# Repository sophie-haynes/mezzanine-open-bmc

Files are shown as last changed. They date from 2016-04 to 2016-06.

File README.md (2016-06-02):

# mezzanine-open-bmc

This project contains the kicad files for the BMC project.

##Project Status
* _Schematic:_ Complete. Would be wise to have a quick review (just to be safe :) ).
* _PCB:_ Connected. DRC appears to throw some small issues, once resolved gerber files can be produced.
* _Footprints:_ Some footprints have been added to the project.

__NOTE:__ There is some strangeness between the schematic and PCB; the ratsnest shows incorrect connections in the PCB so be sure to refer to the schematic when connecting components.

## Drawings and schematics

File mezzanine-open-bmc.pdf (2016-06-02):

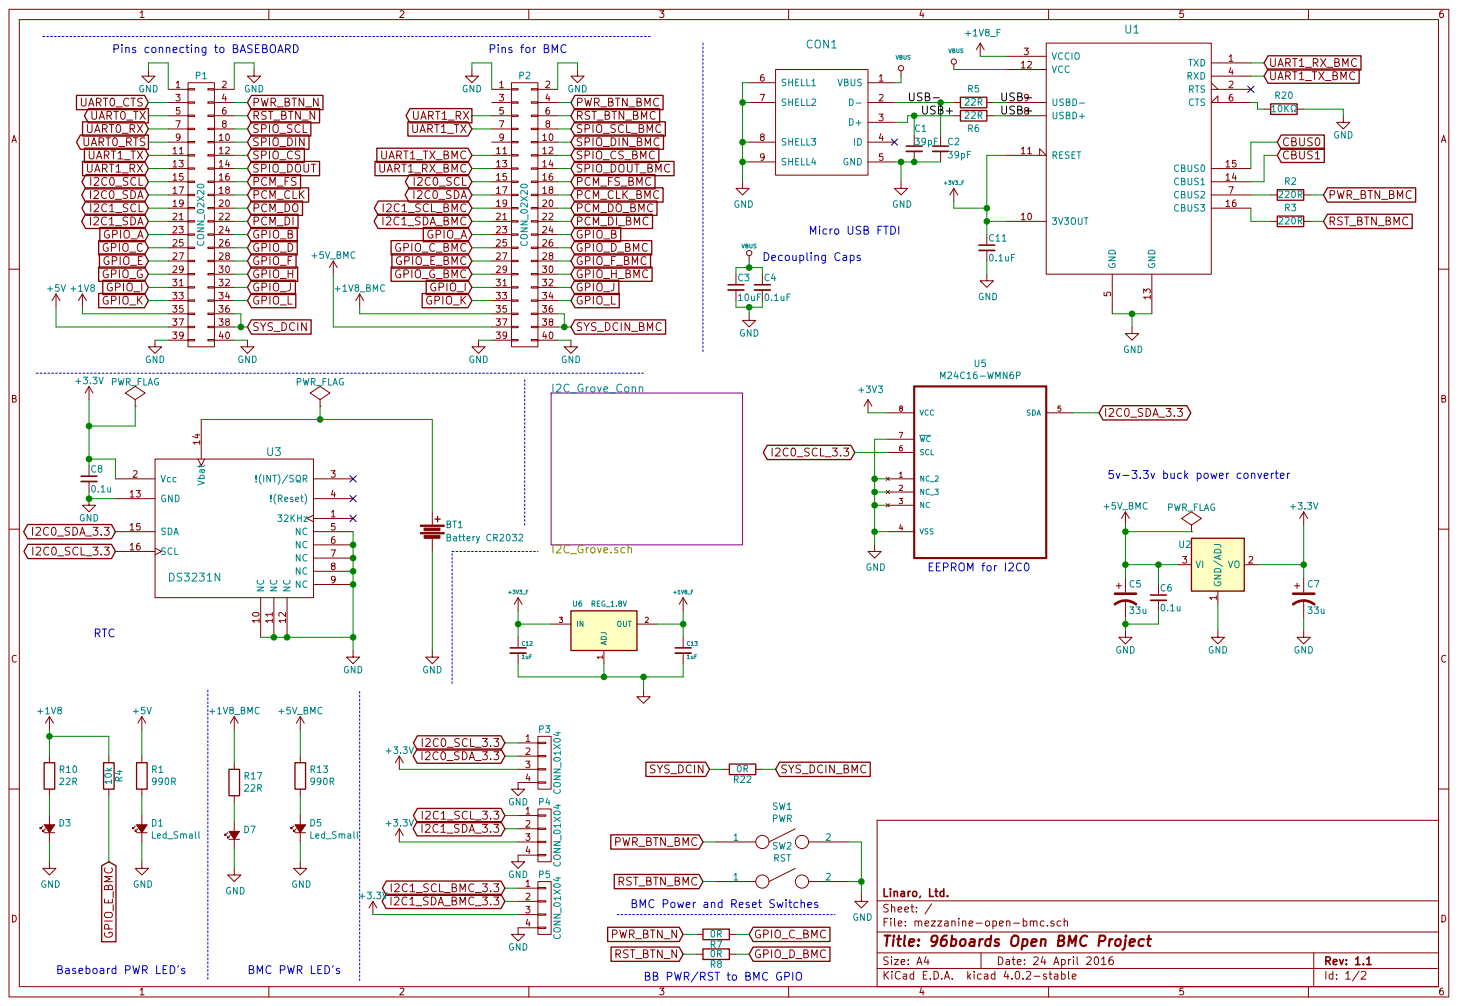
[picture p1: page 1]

BB PWR/RST to BMC GPIO +5V GPIO_E_BMC

File: mezzanine-open-bmc.sch Sheet: / Linaro, Ltd.

Id: 1/2 Title: 96boards Open BMC Project

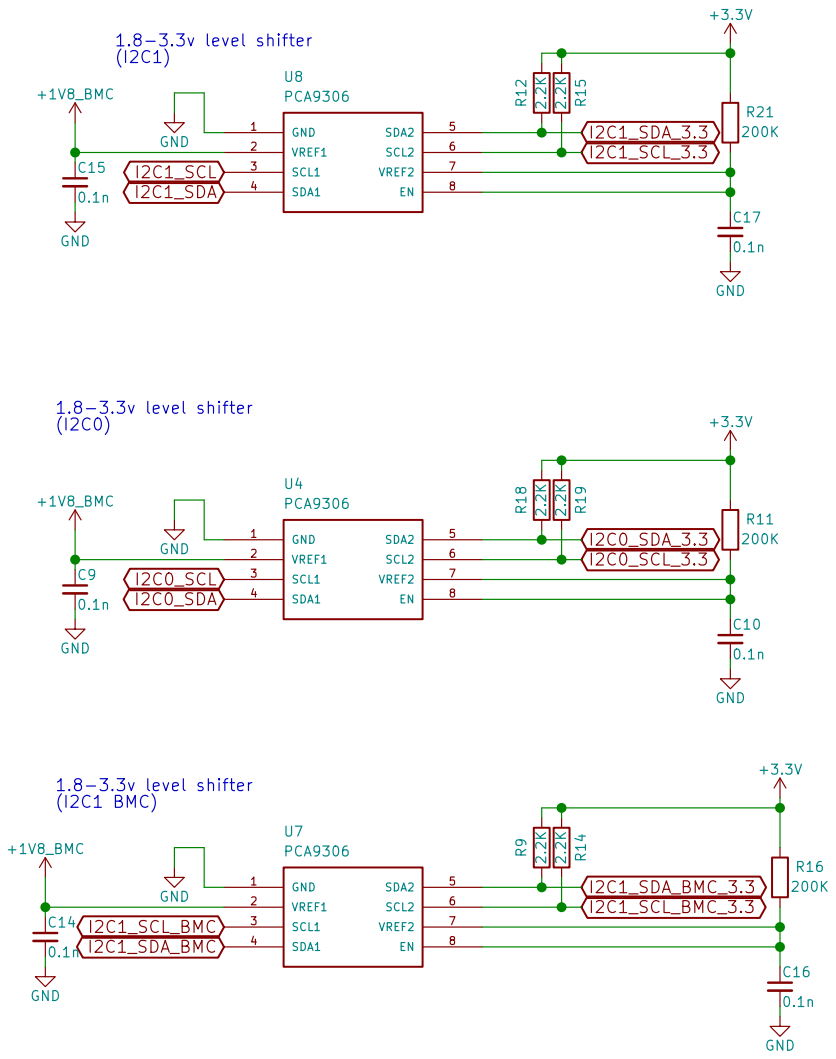
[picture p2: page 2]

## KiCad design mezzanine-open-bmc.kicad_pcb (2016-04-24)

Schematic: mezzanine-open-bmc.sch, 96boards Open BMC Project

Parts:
BT1: Battery CR2032
C1, C2: 39pF; C_0603
C3: 10uF; C_0603
C4, C11: 0.1uF; C_0603
C5, C7: 33u; C_0603
C6: 0.47u; C_0603
C8: 0.1u; C_0603
C9, C10: 0.1n; C_0603
C12, C13: 1uF; C_0603
C14, C15: 100n; C_0603
CON1: USB_MICRO_B_ST-USB-001E
D1, D3, D5, D7: Led_Small; LED_0603
P1: CONN_02X20; Pin_Header_SMD_2x20_Pitch2mm; Mfr Part # P220-1220A0xMxxxx2
P2: CONN_02X20; Pin_Header_SMD_2x20_Pitch2mm; Mfr Part # F240-1220A0xMUx1
P3, P4: CONN_01X04; Grove4P
R1, R13: 90Ω; R_0603
R2, R3: 220R; R_0603
R4: 10k; R_0603
R5, R6: 22R; R_0603
R7, R8: 0R; R_0603
R10, R17: 620R; R_0603
R11: 200k; R_0603
R18, R19: 2.2K; R_0603
R20: 10KΩ; R_0603
SW1: PWR; SW_SPST_B3U-1000P
SW2: RST; SW_SPST_B3U-1000P
U1: FT230XS; SSOP-16_3.9x4.9mm_Pitch0.635mm_Seeed
U2: PMIC-CJT1117-3.3(SOT223); SOT-223
U3: DS3231N; SO-16-W
U4: PCA9306
U5: M24C16-WMN6P; SOIC127P600X175-8N
U6: REG_1.8V; SOT-23_Seeed; Mfr Part # XC6206P182MR
U7: TXS0104PW; SSOP-14_5.3x6.2mm_Pitch0.65mm

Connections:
+3V3: C7.1, C8.1, R11.1, R18.1, R19.2, U2.2, U3.2 (Vcc), U5.8
+3V3_F: C12.1, U6.3
CBUS0: U1.15 (CBUS0)
CBUS1: U1.14 (CBUS1)
GND: BT1.2, C1.2, C2.2, C3.2, C4.2, C5.2, C6.1, C7.2, C8.2, C9.2, C10.2, C11.2, C12.2, C13.2, C14.2, C15.2, CON1.5 (GND), CON1.6 (SHELL1), CON1.7 (SHELL2), CON1.8 (SHELL3), CON1.9 (SHELL4), D1.1 (K), D3.1 (K), D5.1 (K), D7.1 (K), P1.1, P1.2, P1.39, P1.40, P2.1, P2.2, P2.39, P2.40, P3.4, P4.4, R20.1, SW1.2, SW2.2, U1.5 (GND), U1.13 (GND), U2.1, U3.5 (NC), U3.6 (NC), U3.7 (NC), U3.8 (NC), U3.9 (NC), U3.10 (NC), U3.11 (NC), U3.12 (NC), U3.13 (GND), U4.1 (GND), U5.1, U5.2, U5.3, U5.4, U5.7, U6.1, U7.7
GPIO_A: P1.23, P2.23
GPIO_B: P1.24, P2.24
GPIO_C: P1.25
GPIO_C_BMC: P2.25, R7.1
GPIO_D: P1.26
GPIO_D_BMC: P2.26, R8.1
GPIO_E: P1.27
GPIO_E_BMC: P2.27, R4.2
GPIO_F: P1.28
GPIO_F_BMC: P2.28
GPIO_G: P1.29
GPIO_G_BMC: P2.29
GPIO_H: P1.30
GPIO_H_BMC: P2.30
GPIO_I: P1.31, P2.31
GPIO_J: P1.32, P2.32
GPIO_K: P1.33, P2.33
GPIO_L: P1.34, P2.34
I2C0_SCL: P1.15, P2.15, U4.3 (SCL1), U5.6, U7.3
I2C0_SCL/5: P3.1, U7.12
I2C0_SCL_3.3: R19.1, U3.16 (SCL), U4.6 (SCL2)
I2C0_SDA: P1.17, P2.17, U4.4 (SDA1), U5.5, U7.2
I2C0_SDA/5: P3.2, U7.13
I2C0_SDA_3.3: R18.2, U3.15 (SDA), U4.5 (SDA2)
I2C1_SCL: P1.19, U7.5
I2C1_SCL/5: P4.1, U7.10
I2C1_SCL_BMC: P2.19
I2C1_SDA: P1.21, U7.4
I2C1_SDA/5: P4.2, U7.11
I2C1_SDA_BMC: P2.21
unnamed: BT1.1, U3.14 (Vbat)
unnamed: C1.1, CON1.3 (D+), R6.2
unnamed: C2.1, CON1.2 (D-), R5.2
unnamed: C10.1, R11.2, U4.7 (VREF2), U4.8 (EN)
unnamed: C11.1, U1.10 (3V3OUT), U1.11 (RESET)
unnamed: D1.2 (A), R1.2
unnamed: D3.2 (A), R10.2
unnamed: D5.2 (A), R13.2
unnamed: D7.2 (A), R17.2
unnamed: R2.2, U1.7 (CBUS2)
unnamed: R3.2, U1.16 (CBUS3)
unnamed: R5.1, U1.9 (USBD-)
unnamed: R6.1, U1.8 (USBD+)
unnamed: R20.2, U1.6 (CTS)
PCM_CLK: P1.18
PCM_CLK_BMC: P2.18
PCM_DI: P1.22
PCM_DI_BMC: P2.22
PCM_DO: P1.20
PCM_DO_BMC: P2.20
PCM_FS: P1.16
PCM_FS_BMC: P2.16
PWR_BTN_BMC: P2.4, R2.1, SW1.1
PWR_BTN_N: P1.4, R7.2
RST_BTN_BMC: P2.6, R3.1, SW2.1
RST_BTN_N: P1.6, R8.2
SPIO_CS: P1.12
SPIO_CS_BMC: P2.12
SPIO_DIN: P1.10
SPIO_DIN_BMC: P2.10
SPIO_DOUT: P1.14
SPIO_DOUT_BMC: P2.14
SPIO_SCL: P1.8
SPIO_SCL_BMC: P2.8
SYS_DCIN: P1.36, P1.38
SYS_DCIN_BMC: P2.36, P2.38
UART0_CTS: P1.3
UART0_RTS: P1.9
UART0_RX: P1.7
UART0_TX: P1.5
UART1_RX: P1.13, P2.5
UART1_RX_BMC: P2.13, U1.1 (TXD)
UART1_TX: P1.11, P2.7
UART1_TX_BMC: P2.11, U1.4 (RXD)
VBUS: C3.1, C4.1, CON1.1 (VBUS), U1.12 (VCC)

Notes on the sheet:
Pins connecting to BASEBOARD
Pins for BMC
BMC Power and Reset Switches
BB PWR/RST to BMC GPIO
Baseboard PWR LED's
Micro USB FTDI
1.8v-3.3v level shifter
5v-3.3v buck power converter
RTC
BMC PWR LED's
Decoupling Caps
EEPROM for I2C0

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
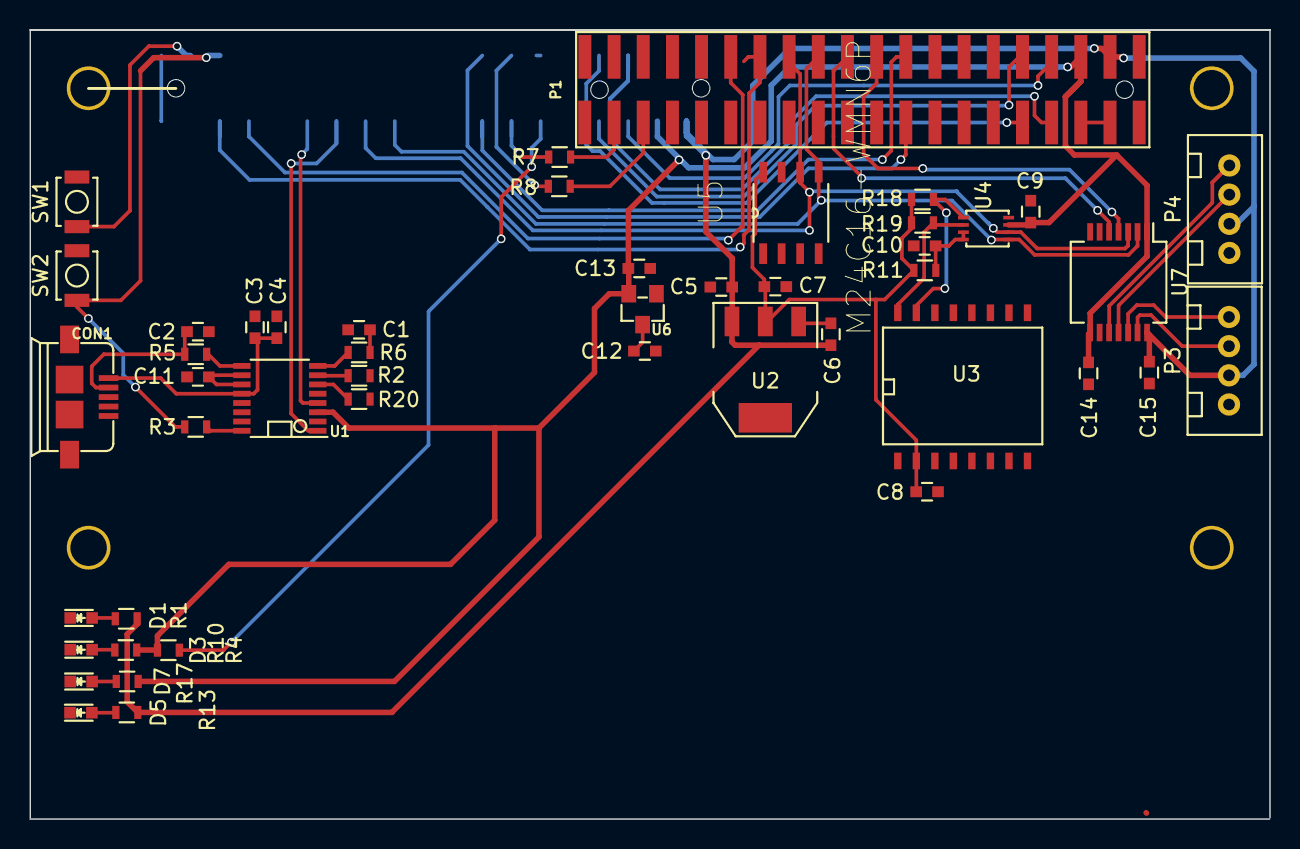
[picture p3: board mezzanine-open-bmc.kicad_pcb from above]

Board: 2 copper layers, 85.0 x 54.1 mm, 48 parts (1 on the bottom side), 48 nets.

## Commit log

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2016-03-01 Connect BB UART1 to BMC UART1
    All pins on the BMC header pins now have "_BMC" appended to their signal
    names. This is to allow connections to be made from different pins on the
    BB (Baseboard).
    UART1 on the BB is now connected to UART1 on the BMC
    [mezzanine-open-bmc.sch]
2016-03-01 Connect BB GPIO_A/B to BMC GPIO_A/B
    GPIO A & B are now connected on the BB to the BMC.
    [mezzanine-open-bmc.sch]
2016-03-01 Connect BB PWR/RST to BMC GPIO
    The BB PWR BTN is now wired to BMC GPIO C.
    BB RST BTN is wired to BMC GPIO D.
    [mezzanine-open-bmc.sch]
2016-03-01 Connect BB 1V8 to BMC GPIO_E, Make New Library
    The BB 1V8 is wired up to BMC GPIO_E.
    [mezzanine-open-bmc.sch]
2016-03-01 Connect FTDI to BMC UART1
    A microUSB is now connected to UART1.
    [mezzanine-open-bmc.sch]
2016-03-10 Change Signal Names for GPIO_A/B BMC
    Since GPIO_A and GPIO_B are to be connected on the BB & BMC pins,
    the signal names have been renamed to match.
    [mezzanine-open-bmc.sch]
2016-03-10 Add 22R to GPIO_B_BMC, Add to BMC Lib
    To protect the board, a resistor has been added to the GPIO line
    [mezzanine-open-bmc.sch]
2016-03-10 Add Decoupling Caps to FTDI
    Decoupling capacitors were missing from the schematic. These have been added
    (including footprints).
    [mezzanine-open-bmc.sch]
2016-03-15 Add Level Shifter to Schematic
    First attempt at wiring up pca9306 level shifter to the I2C buses.
    VCC power is likely to be wrong.
    [mezzanine-open-bmc.sch]
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2016-03-22 Append New Schematic to Current Working Schematic
    A new schematic containing a level shifter (1.8v-3.3v), buck power converter
    (5v-3.3v) and RTC.
    This is a rough append; it is likely signal name changes will be required.
    [mezzanine-open-bmc.sch]
2016-03-25 Tidy sch lines and include new footprints, Assign footprints
    Changes:
    *Rename GPIO_A/B (remove BB_BMC)
    *Include footprints (SSOP-16, USB-MICRO, SOT-23)
    *Include decoupling caps
    *Add LED & transistor for 1v8 line
    *Fix shifted layout
    *Remove redundant level shifter
    *Start assigning footprints
    [mezzanine-open-bmc.sch]
2016-03-29 Add LED's to BMC PWR Lines
    LED's have been added to the BMC 5v & 1v8 power lines. This will indicate
    when the board is powered up.
    [mezzanine-open-bmc.sch]
2016-03-30 Assign More Footprints, Position Header
    This commit add footprints to switches and the High Speed Connector (PCA9306).
    In the PCB, the header pins are in the correct position now so that the two
    stacking HiKey boards will be attatched one the same side and power ports
    will be coming out of the same side.
    [mezzanine-open-bmc.kicad_pcb, mezzanine-open-bmc.sch]
2016-03-30 Group Components on PCB
    Components have been grouped in the PCB to make it tidier and make positioning
    easier.
    [mezzanine-open-bmc.kicad_pcb, mezzanine-open-bmc.sch]
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2016-04-04 Remove LED, Connect Remaining GPIO
    LED is not required for RTC unit so has been removed.
    The remaining unconnected GPIO have been connected so the the BMC board
    can access them,
    [mezzanine-open-bmc.sch]
2016-04-04 Change Value of C3 & C4
    Capacitor values for the decoupling capaitors have been
    changed to 10uF
    [mezzanine-open-bmc.sch]
2016-04-04 Remove PWR from FT230XS Pin 10, Add Capacitor
    Pin 10 already gets power from LDO, so additional 3v3
    power has been removed.
    Capacitor has been added for safety :)
    Decoupling caps has been moved closer to the VBUS signals
    to show they need to be close together.
    [mezzanine-open-bmc.sch]
2016-04-04 Pull Down CTS on FT230XS
    So that this pin is not "floating", it has been pulled down with a
    10KΩ resistor.
    [mezzanine-open-bmc.sch]
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2016-04-06 Change PWR Converter & Fix Library Issues/Confusing Jiggery Pokery
    This commit attempts to fix loading issues with libraries
    and footprints. The correct footprint for SOT-233 has been applied
    to the 5v-3v3 buck power converted and has been tweaked as needed.
    [mezzanine-open-bmc.sch]
2016-04-06 Connect Header Pins
    This is a first draft of the connections between the two header pins. This layout
    may not be the most efficient therefore is likely to be changed.
    [mezzanine-open-bmc.kicad_pcb]
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2016-04-11 Alternative Traces for Header Pins
    Since most components will be sitting on the top side of the
    device, traces for the header pins have been drawn on the bottom side
    as much as possible. This should mean it will be easier to connect the
    rest of the components.
    A new branch has been made to preserve the former trace layout if this
    version is no good.
    [mezzanine-open-bmc.kicad_pcb]
2016-04-11 Add New Footprints and Assign to Transistors
    Footprints have been added to the .pretty folder.
    Footprint for the transistors Q1 & Q2 have been assigned.
    [mezzanine-open-bmc.sch]
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2016-04-13 Add EEPROM for I2C Lines to Schematic
    First attempt at connecting i2c lines to EEPROM. Currently only connected to
    the BMC pins. This will be changed so it is also connected to the baseboard
    i2c
    [mezzanine-open-bmc.sch]
2016-04-13 Remove "_BMC" Suffix From I2C0 Lines
    To improve i2c connections with the EEPROM, signal names
    have been changed.
    [mezzanine-open-bmc.sch]
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2016-04-20 Create Correct Footprint for PCA9306, Assign Footprint, Connect U4
    The PCA footprint was incorrect. This has been fixed; there are two
    different models so both types have been added. It has been assigned
    accordingly in the schematic.
    U4(level shifter 1.8-3.3v) has been connected up.
    [mezzanine-open-bmc.kicad_pcb, mezzanine-open-bmc.sch]
2016-04-20 Wire Up FTDI
    The wiring for the FTDI components have been connnected up in a neat
    little bundle which can be placed on the board.
    [mezzanine-open-bmc.kicad_pcb]
2016-04-20 Wire Up BB LED (1.8v)
    The wiring for the LED components of 1.8 have been connnected up in a neat little
    bundle which can be placed on the board.
    [mezzanine-open-bmc.kicad_pcb, mezzanine-open-bmc.sch]
2016-04-20 Wire Up BMC LED's
    The wiring for the BMC PWR LED's have been connnected up in a neat
    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
    [mezzanine-open-bmc.kicad_pcb]
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2016-04-24 Add Grove Connectors for I2C
    The two I2C lines have now been wired to two grove connectors and passed
    through level shifter to 5v
    [mezzanine-open-bmc.sch]
2016-04-24 Connect Up Components
    All components are connected (barring the battery since there is no
    footprint currently)
    [mezzanine-open-bmc.kicad_pcb, mezzanine-open-bmc.sch]
2016-04-25 Complete PCB Layout and Include Missing Footprints (BT1, C5, C7)
    The missing footprints have been added to both the schematic and the PCB.
    Capacitor values for C6 have been changes to 0.1uF.
    The new components have been connected up in the PCB.
    [mezzanine-open-bmc.kicad_pcb, mezzanine-open-bmc.sch]
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2016-05-04 Swap Location of P1/P2
    The BMC board should be on the top, so the pin header have been switched
    accordingly.
    [mezzanine-open-bmc.kicad_pcb]
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2016-05-18 [WIP] Just several GPIO require connecting
    Most components are connected now. I dislike the bunching of traces, and some
    1v8 lines are quite long which is bad for interference.
    The bunching of all the traces so close to the pins is causing issues getting
    the last connectors connected. I may have to move the LS down, and move all the
    traces down too. :(
    [mezzanine-open-bmc.kicad_pcb]
2016-05-18 [WIP] Just several GPIO require connecting
    the last connectors connected. I may have to move the regulators down,
    and move all the traces down too. :(
    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
    [mezzanine-open-bmc.kicad_pcb]
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
